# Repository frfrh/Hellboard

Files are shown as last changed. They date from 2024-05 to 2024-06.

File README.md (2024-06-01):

# Hellboard

This is a Macro board based on RP2040-zero and Micropython, meant for ordering Stratagems for Helldivers 2 by registering as a HID-Keyboard.

PXL_20240601_011015119 MP

## Folders

##### [Firmware](https://github.com/frfrh/Hellboard/tree/master/Firmware)

Contains the firmware to be loaded into the RP2040 and the Micropython project files.

##### [Hardware](https://github.com/frfrh/Hellboard/tree/master/Hardware)

Contains the 3D files for the case and the button caps.

##### [PCB](https://github.com/frfrh/Hellboard/tree/master/PCB)

Contains the project files for the PCB and the gerber files to order one.
Project is based on KiCad 8.0.2.

## Configuration

Currently the configuration of the board is hardcoded. This is meant to change in (near) future.

You can change the stratagems assigned to the buttons at the top on [main.py](https://github.com/frfrh/Hellboard/blob/master/Firmware/main.py) by replacing the macros for `button_2_1`, `button_2_2`, `button_2_3` and `button_2_4`.

You can change the directional keys in https://github.com/frfrh/Hellboard/blob/master/Firmware/libs/macro.py.

You can change the modifyer key in https://github.com/frfrh/Hellboard/blob/master/Firmware/libs/helldiver.py. `modifierUseToggle = True` means that the button will only be pressed once to open the menue, `modifierUseToggle = False` means that the button stay pressed while entering the macro.

## Build your own

You can use the gerber files in [PCB/gerber](https://github.com/frfrh/Hellboard/tree/master/PCB/gerber) to order your own PCBs or order it directly from https://aisler.net/p/AHPZGPKK.

You will also need the following parts:

| Part | Amount | Link |
| - | - | - |
| RP2040-Zero | 1 | [link](https://www.waveshare.com/rp2040-zero.htm) |
| 0,96" OLED Display 128x64 | 1 | [link](https://de.aliexpress.com/item/1005005970901119.html) (the 26.7mm variant, blue PCB) |
| Kailh boxed switches | 8 | [link](https://www.caseking.de/ducky-kailh-box-navy-switches-mechanisch-3-pin-clicky-mx-stem-85g-110-stueck-gakc-444.html) |
| Kailh hot-swap socket | 8 | [link](https://de.aliexpress.com/item/1005006146911562.html) |
| WS2812b-2020 LED | 8 | [link](https://de.aliexpress.com/item/10000006244752.html) |
| N-Channel MOSFET[^levelshifter] | 1 |  |
| 10K 0805 resistor[^levelshifter] | 2 |  |
| M93C86-WMN6P EEPROM[^eeprom] | 1 | [link](https://www.reichelt.de/eeprom-seriell-16kb-2kx8-1kx16-2-5-5v-so-8-m93c86-wmn6p-p280935.html) |
| Button caps[^buttoncaps] | 8 | [link](https://de.aliexpress.com/item/1005003992982246.html) |

You can find icons for the buttons [here](https://github.com/nvigneux/Helldivers-2-Stratagems-icons-svg).

## Setup

1. Install [Visual Studio Code](https://code.visualstudio.com/).
2. Install the [MicroPico extension](https://marketplace.visualstudio.com/items?itemName=paulober.pico-w-go).
3. Flash the firmware onto the RP2040:
    1. Press the button (`Boot`) and connect the Board to a PC.
    2. Copy the [UF2-file](https://github.com/frfrh/Hellboard/blob/master/Firmware/libs/3rd/firmware_with_HID_support.v.1.17.uf2) into the drive `RPI-RP2`.
    3. Re-Connect the board.
4. Load the following Python files into the board. In Visual Studio Code left click on the file, then right click the file and select `Upload current file to Pico`.
    - `Firmware/libs/3rd/keyboard.py`
    - `Firmware/libs/3rd/ssd1306.py`
    - `Firmware/libs/helldiver.py`
    - `Firmware/libs/macro.py`
    - `Firmware/main.py`

[^levelshifter]: I got them by desoldering them from a level shifter I had lying around. [link](https://de.aliexpress.com/item/1005006068381598.html)
[^eeprom]: The EEPROM is currently optional. This is meant for future configuration of the loaded stratagems, currently those are hardcoded.
[^buttoncaps]: I used the button caps from [here](https://de.aliexpress.com/item/1005003992982246.html) but replaced the internals with the ones from `Hardware/Kailh-Cap.stl` as the original ones are not translucent. Any button caps compatible with Kailh boxed switches should do.

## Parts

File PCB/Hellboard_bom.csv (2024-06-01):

Reference | Value | Datasheet | Footprint | Qty | DNP
C1,C2,C3,C4,C5,C6,C7,C8 | 4µ7 | ~ | Capacitor_SMD:C_0805_2012Metric_Pad1.18x1.45mm_HandSolder | 8 | Nicht bestücken
CR1 | M93C66-WMN6P | https://www.st.com/resource/en/datasheet/m93c46-w.pdf | footprints_M93C66-WMN6P:SO-8_STM | 1
D1,D2,D3,D4,D5,D6,D7,D8 | WS2812_Switch | https://cdn-shop.adafruit.com/product-files/4684/4684_WS2812B-2020_V1.3_EN.pdf | -- verschiedene Werte -- | 8
J1 | OLED-128x64 | https://www.datasheethub.com/ssd1306-128x64-mono-0-96-inch-i2c-oled-display/ | display:OLED-128x64 | 1
Q1 | AO3400A | http://www.aosmd.com/pdfs/datasheet/AO3400A.pdf | Package_TO_SOT_SMD:SOT-23 | 1
R1,R2 | 10k | ~ | LED_SMD:LED_0805_2012Metric_Pad1.15x1.40mm_HandSolder | 2
TP1,TP2,TP3,TP4,TP5,TP6,TP7,TP8,TP9 | TestPoint | ~ | TestPoint:TestPoint_Pad_D1.5mm | 9
U1 | rp2040-zero | https://www.waveshare.com/rp2040-zero.htm | mcu:rp2040-zero-smd | 1

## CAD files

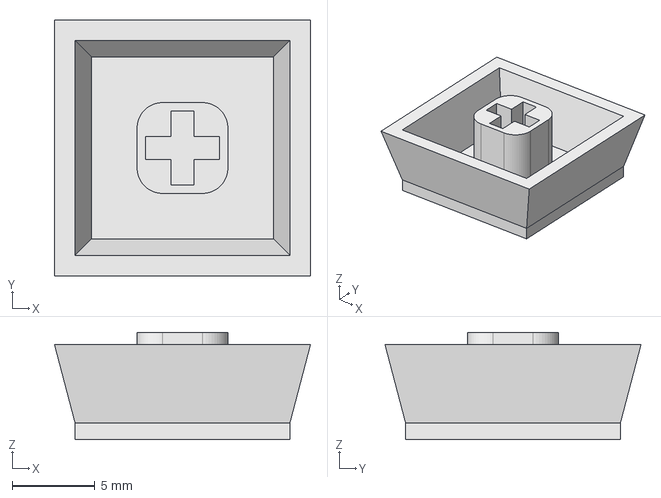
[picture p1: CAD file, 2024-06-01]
Hardware/Kailh-Cap.FCStd
15.5 x 15.5 x 6.50 mm

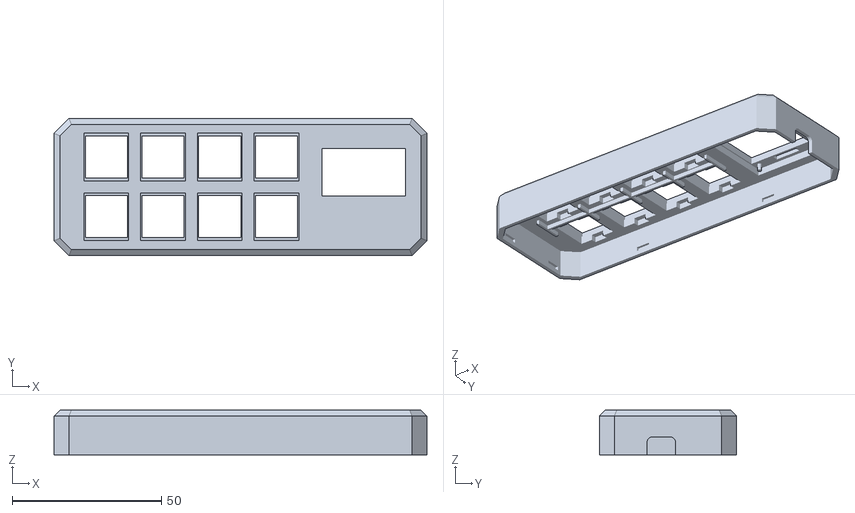
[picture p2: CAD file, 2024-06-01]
Hardware/Hellboard-Case-Top.stl
125.0 x 46.0 x 15.0

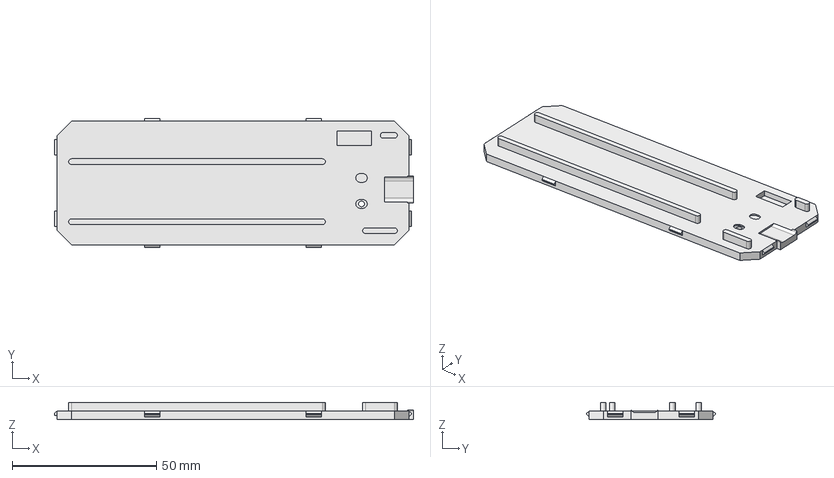
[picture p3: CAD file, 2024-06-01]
Hardware/Hellboard-Case.FCStd
124.3 x 44.6 x 6.00 mm

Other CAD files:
Hardware/Hellboard-Case-Bottom.stl
Hardware/Kailh-Cap.stl

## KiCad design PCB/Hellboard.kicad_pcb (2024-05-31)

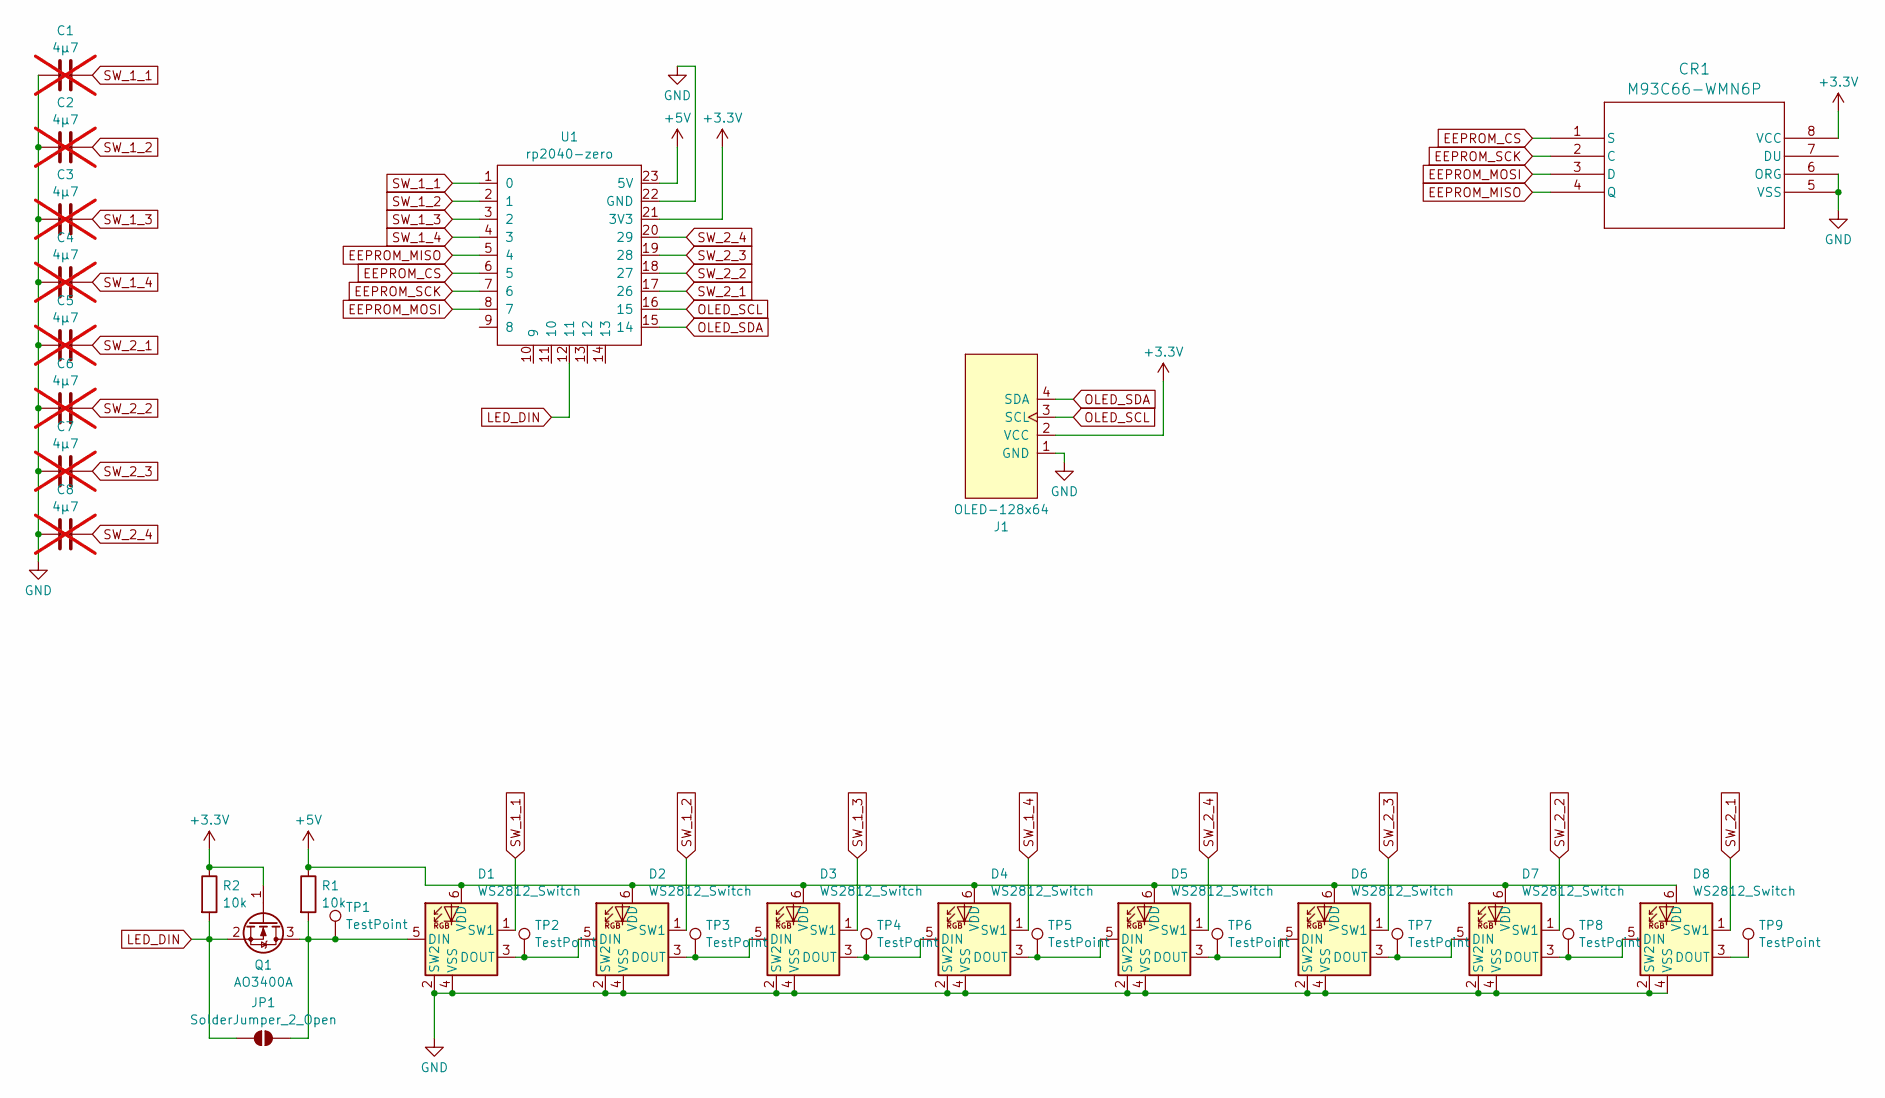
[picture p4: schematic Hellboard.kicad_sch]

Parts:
C1, C2, C3, C4, C5, C6, C7, C8: 4µ7; C_0805_2012Metric_Pad1.18x1.45mm_HandSolder; not fitted
CR1: M93C66-WMN6P; SO-8_STM
D1, D2, D3, D4: WS2812_Switch; Kailh_socket_MX_WS2812B_RL
D5, D6, D7, D8: WS2812_Switch; Kailh_socket_MX_WS2812B_LR
J1: OLED-128x64
JP1: SolderJumper_2_Open; SolderJumper-2_P1.3mm_Open_TrianglePad1.0x1.5mm
Q1: AO3400A; SOT-23
R1, R2: 10k; LED_0805_2012Metric_Pad1.15x1.40mm_HandSolder
TP1, TP2, TP3, TP4, TP5, TP6, TP7, TP8, TP9: TestPoint; TestPoint_Pad_D1.5mm
U1: rp2040-zero; rp2040-zero-smd

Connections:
+3.3V: CR1.8 (VCC), J1.2 (VCC), Q1.1 (G), R2.1, U1.21 (3V3)
+5V: D1.6 (VDD), D2.6 (VDD), D3.6 (VDD), D4.6 (VDD), D5.6 (VDD), D6.6 (VDD), D7.6 (VDD), D8.6 (VDD), R1.1, U1.23 (5V)
EEPROM_CS: CR1.1 (S), U1.6 (5)
EEPROM_MISO: CR1.4 (Q), U1.5 (4)
EEPROM_MOSI: CR1.3 (D), U1.8 (7)
EEPROM_SCK: CR1.2 (C), U1.7 (6)
GND: C1.1, C2.1, C3.1, C4.1, C5.1, C6.1, C7.1, C8.1, CR1.5 (VSS), CR1.6 (ORG), D1.2 (SW2), D1.4 (VSS), D2.2 (SW2), D2.4 (VSS), D3.2 (SW2), D3.4 (VSS), D4.2 (SW2), D4.4 (VSS), D5.2 (SW2), D5.4 (VSS), D6.2 (SW2), D6.4 (VSS), D7.2 (SW2), D7.4 (VSS), D8.2 (SW2), D8.4 (VSS), J1.1 (GND), U1.22 (GND)
LED_DIN: JP1.1 (A), Q1.2 (S), R2.2, U1.12 (11)
unnamed: D1.5 (DIN), JP1.2 (B), Q1.3 (D), R1.2, TP1.1
unnamed: D1.3 (DOUT), D2.5 (DIN), TP2.1
unnamed: D2.3 (DOUT), D3.5 (DIN), TP3.1
unnamed: D3.3 (DOUT), D4.5 (DIN), TP4.1
unnamed: D4.3 (DOUT), D5.5 (DIN), TP5.1
unnamed: D5.3 (DOUT), D6.5 (DIN), TP6.1
unnamed: D6.3 (DOUT), D7.5 (DIN), TP7.1
unnamed: D7.3 (DOUT), D8.5 (DIN), TP8.1
unnamed: D8.3 (DOUT), TP9.1
OLED_SCL: J1.3 (SCL), U1.16 (15)
OLED_SDA: J1.4 (SDA), U1.15 (14)
SW_1_1: C1.2, D1.1 (SW1), U1.1 (0)
SW_1_2: C2.2, D2.1 (SW1), U1.2 (1)
SW_1_3: C3.2, D3.1 (SW1), U1.3 (2)
SW_1_4: C4.2, D4.1 (SW1), U1.4 (3)
SW_2_1: C5.2, D8.1 (SW1), U1.17 (26)
SW_2_2: C6.2, D7.1 (SW1), U1.18 (27)
SW_2_3: C7.2, D6.1 (SW1), U1.19 (28)
SW_2_4: C8.2, D5.1 (SW1), U1.20 (29)

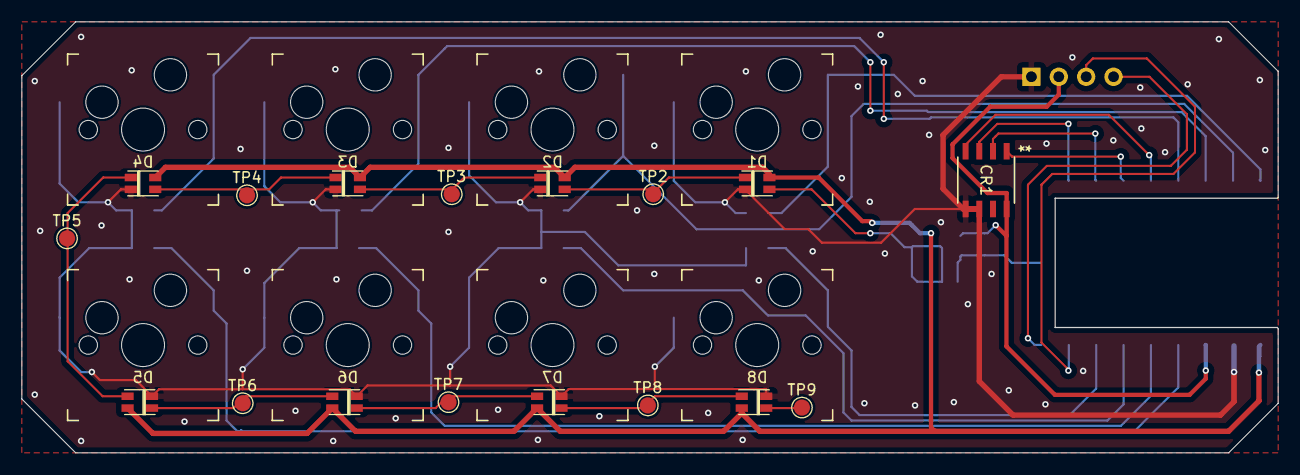
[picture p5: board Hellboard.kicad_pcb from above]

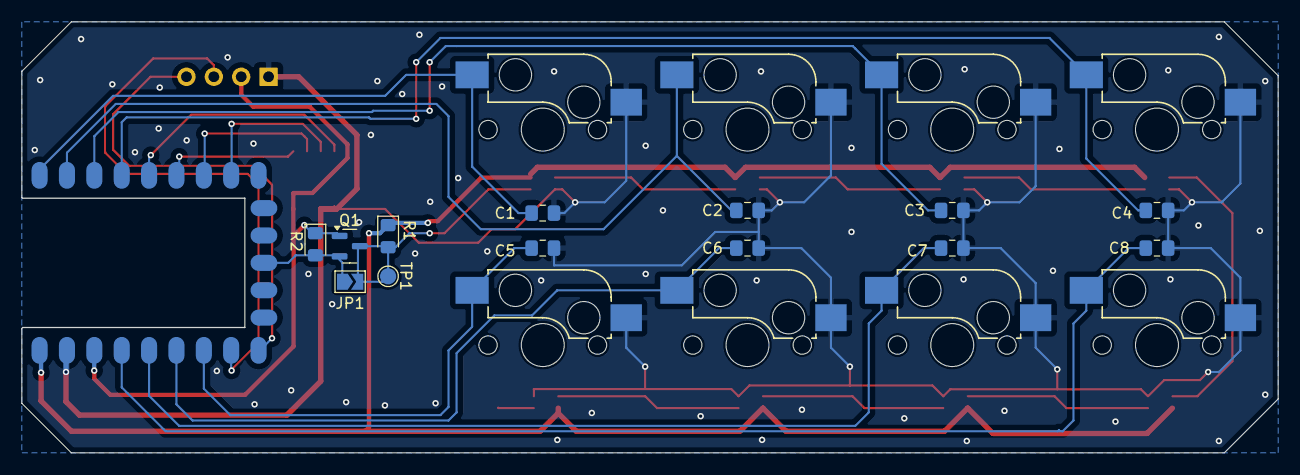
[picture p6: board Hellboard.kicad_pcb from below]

Board: 2 copper layers, 116.6 x 40.0 mm, 32 parts (14 on the bottom side), 27 nets.

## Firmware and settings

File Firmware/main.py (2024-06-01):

from machine import Pin, I2C, SPI
from ssd1306 import SSD1306_I2C
import keyboard
from helldiver import Hellboard, Hellbutton
from macro import Macros, Color
import framebuf
import time

k = keyboard.Keyboard()
board = Hellboard(k)

WIDTH = 128 # oled display width
HEIGHT = 64 # oled display height

BRIGHTNESS = 0x50
BRIGHTNESS_CONFIRM = 0x80

b1_4 = Pin(0, Pin.IN, Pin.PULL_UP)
b1_3 = Pin(1, Pin.IN, Pin.PULL_UP)
b1_2 = Pin(2, Pin.IN, Pin.PULL_UP)
b1_1 = Pin(3, Pin.IN, Pin.PULL_UP)

b2_1 = Pin(29, Pin.IN, Pin.PULL_UP)
b2_2 = Pin(28, Pin.IN, Pin.PULL_UP)
b2_3 = Pin(27, Pin.IN, Pin.PULL_UP)
b2_4 = Pin(26, Pin.IN, Pin.PULL_UP)

button_1_1 = Hellbutton(b1_1, Macros.Reinforce)
button_1_2 = Hellbutton(b1_2, Macros.Resupply)
button_1_3 = Hellbutton(b1_3, Macros.Reinforce)
button_1_4 = Hellbutton(b1_4, Macros.CYCLE)

button_2_1 = Hellbutton(b2_1, Macros.GrenadeLauncher)
button_2_2 = Hellbutton(b2_2, Macros.ShieldGeneratorPack)
button_2_3 = Hellbutton(b2_3, Macros.MortarSentry)
button_2_4 = Hellbutton(b2_4, Macros.Eagle500KGBomb)

row1List = []
row1List.append (Macros.SOSBeacon)
row1List.append (Macros.EagleRearm)
row1List.append (Macros.SuperEarthFlag)
row1List.append (Macros.SEAFArtilery)
row1List.append (Macros.UploadData)
row1List.append (Macros.SeismicProbe)
row1List.append (Macros.Hellbomb)
row1List.append (Macros.OrbitalIlluminationFlare)

colors = {}

time.sleep_ms(100)
displayReady = False
try:
    i2c = I2C(1, sda=Pin(14), scl=Pin(15))  # Init I2C using I2C0 defaults, SCL=Pin(GP9), SDA=Pin(GP8), freq=400000
    oled = SSD1306_I2C(WIDTH, HEIGHT, i2c, addr=0x3C) # Init oled display
    time.sleep_ms(100)
    oled.rotate(1)
    print("Display initialized")
    displayReady = True
except Exception:
    print("Display error " + str(Exception))

# Initialize SPI
spiLed = SPI(1,
            baudrate=2500000,
            polarity=1,
            phase=1,
            bits=8,
            firstbit=SPI.MSB,
            sck=Pin(10),
            mosi=Pin(11),
            miso=Pin(12))

# 1/2 mix
def byteToData(byte):
    # Initialize all `0`
    data = bytearray(b'\x92\x49\x24')
    data[0] |= 0x01 if (byte & 0x20) else 0
    data[0] |= 0x08 if (byte & 0x40) else 0
    data[0] |= 0x40 if (byte & 0x80) else 0
    data[1] |= 0x04 if (byte & 0x08) else 0
    data[1] |= 0x20 if (byte & 0x10) else 0
    data[2] |= 0x02 if (byte & 0x01) else 0
    data[2] |= 0x10 if (byte & 0x02) else 0
    data[2] |= 0x80 if (byte & 0x04) else 0
    return data

def rbgToData(r, g, b):
    data = bytearray()
    # print ("Adding R:" + str(r) + ", G:" + str(g) + ", B:" + str(b))
    data.extend(byteToData(g))
    data.extend(byteToData(r))
    data.extend(byteToData(b))
    return data

def intToData(color):
    # print ("Adding color: 0x{0:02x}".format(color))
    return rbgToData(((color>>16)&0xFF),
                     ((color>>8)&0xFF),
                     ((color)&0xFF))

buttons = []
buttons.append(button_1_4)
buttons.append(button_1_3)
buttons.append(button_1_2)
buttons.append(button_1_1)
buttons.append(button_2_1)
buttons.append(button_2_2)
buttons.append(button_2_3)
buttons.append(button_2_4)

index = 0
lastTime = time.ticks_ms()
switchTimeout = 300
brightnessConfirm = (BRIGHTNESS_CONFIRM<<16) + (BRIGHTNESS_CONFIRM<<8) + (BRIGHTNESS_CONFIRM)

def doButtons():
    global index
    global lastTime
    pressed = False
    for button in buttons:
        if button.isPressed():
            if button.getMacro() == Macros.CYCLE:
                if (lastTime + switchTimeout) < time.ticks_ms():
                    lastTime = time.ticks_ms()
                    index = index + 1
                    if index >= len(row1List):
                        index = 0
                    pressed = True
                    button_1_3.setMacro(row1List[index])
                    print("Button 1-3 set to: \"" + button_1_3.getMacro().getName() + "\"")
            else:
                print(button.getMacro())
                board.sendMacro(button.getMacro())
                pressed = True

    return pressed

def doDisplay():
    global displayReady
    if displayReady:
        oled.fill(0)
        oled.text(button_1_3.getName(),0,4)
        oled.text("----------------",0,18)
        oled.text(button_2_1.getName(),0,24)
        oled.text(button_2_2.getName(),0,34)
        oled.text(button_2_3.getName(),0,44)
        oled.text(button_2_4.getName(),0,54)
        oled.show()

def doLed(buttonPressed):
    global brightnessConfirm
    data = bytearray()
    if buttonPressed:
        for x in range(8):
            data.extend(intToData(brightnessConfirm))
    else:
        for button in buttons:
            data.extend(intToData(colors[button.getMacro().getColor()]))
    spiLed.write(data)


# MAIN 

print (spiLed)
print ("Brightness set to " + str((BRIGHTNESS * 100) / 255) + "%")
button_1_3.setMacro(row1List[index])

colors[Color.YELLOW] = (BRIGHTNESS<<16) + (BRIGHTNESS<<8)
colors[Color.RED] = (BRIGHTNESS<<16)
colors[Color.GREEN] = (BRIGHTNESS<<8)
colors[Color.BLUE] = (BRIGHTNESS)
colors[Color.WHITE] = (BRIGHTNESS<<16) + (BRIGHTNESS<<8) + (BRIGHTNESS)

while True:
    pressed = doButtons()
    doDisplay()
    doLed(pressed)
    
    time.sleep_ms(50)
    

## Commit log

2024-05-31 adding Hellboard PCB
    [Hellboard.kicad_pcb, Hellboard.kicad_sch]
2024-06-01 add case
    [Hellboard-Case-Bottom.stl, Hellboard-Case-Top.stl, Hellboard-Case.FCStd]
2024-06-01 add datasheets
    [Hellboard.kicad_sch]
2024-06-05 fix 120mm barrage
2026-10-15 Detect Helldivers 2 window and monitor (P1)
    - IGameLocator with GameSnapshot/GameLocation model in Core
    - Monitor selection (largest intersection, nearest, override) and
    window mode rules with unit tests, incl. negative coordinates
    - Win32GameLocator: WinEvent hooks + 1 s polling on its own message
    loop thread, per-monitor DPI aware independent of the host manifest
    - Game section in the status window
    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
2026-10-15 Capture the game monitor via Desktop Duplication (P2)
    - Frame, IFrameSource and GameFrameGrabber in Core (platform-neutral)
    - DesktopDuplicationFrameSource: one duplication session per monitor,
    staging texture, region readback, recreation on access loss
    - Status window: live preview at 2 frames/s, black-frame warning,
    snapshot saving and opening the snapshot folder
    - Unit tests for Frame and GameFrameGrabber
    - Plan: Desktop Duplication replaces Windows.Graphics.Capture as the
    primary capture path; P2 accepted (0.25 % CPU at 2560x1440, 2 fps)
2026-10-15 Add local scene tests and ready status detection (P4, part 1)
    - OpenCvSharp4 for test image loading; LocalScenes loads the local
    screenshots, crops the client area and rescales to 720p-4K in memory,
    skipping scenes whose image is missing
    - tests/testData/scenes.json with expected results (images stay local)
    - ReadyStatusDetector: yellow share of the ready button's inner area,
    Prepare 6-8 %, Ready 71-73 % on all scenes and resolutions
    - stratagem-names-de.md: English/German names of 89 stratagems
    - Plan: stratagem coverage decision, test strategy
2026-10-15 Detect the loadout screen from structural cues (P4, part 2)
    - LoadoutScreenDetector: ready button (yellow outline or fill, block-wise
    diagonal stripe check independent of the label), player slot raster
    (gray inner edges) and fixed mission frames as supporting cue
    - Center-based offset correction (Ready fill is smaller than the
    Prepare outline), verified with shifted captures
    - Tests on all local scenes at 720p-4K: 30 loadout screens detected,
    65 other screens rejected
    - Plan updated with the implemented cues and measured scores
2026-10-15 Classify stratagem slots with SVG-rendered templates (P4, part 3)
    - StratagemIcon (ids are slugs of the repository file names) and a
    minimal StratagemIconDownloader for a local copy of the icon repo
    - SvgRenderer (Svg.Skia 5.1.1 on SkiaSharp 3.119, as used by Avalonia)
    - StratagemSlotClassifier: canonical 64 px, shift tolerance, empty
    detection, score/margin acceptance; slot styles for player slots and
    framed mission slots measured on captures
    - Tests: player and mission slots correct in all scenes at 720p-4K
    against all 109 icons; icons cached in tests/testData/local/icons
2026-10-15 Add recognition pipeline and loadout lock-in (P4, part 4)
    - LoadoutRecognizer: screen detection, ready status and parallel slot
    classification per frame; coarse-to-fine matching and per-slot result
    cache (unchanged loadout 2-11 ms, new loadout 75-140 ms)
    - LoadoutTracker: stable candidate, Prepare->Ready lock-in, screen-exit
    lock-in, Ready->Prepare reset, debouncing; unit and replay tests
    - LoadoutPipeline background loop, StratagemIconStore (runtime icon
    download into the data directory), LoadoutHistory (loadouts.jsonl)
    - Status window shows screen, ready state, stratagems and last lock-in
2026-10-15 Add manual trigger and image file analysis (P4, part 5)
    - Hotkey model and IGlobalHotkeys; Win32GlobalHotkeys via RegisterHotKey
    on a dedicated message thread (no keyboard hook, no input injection)
    - RecognitionOptions (mode, Ctrl+Shift+F9, test mode, snapshot saving)
    - LoadoutPipeline executes manual bursts (5 frames, majority vote) and
    file analyses on its own thread; forced recognition with warning when
    the loadout screen is not detected; manual-only mode
    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
2026-10-16 Record firmware decisions F1-F10
    - F1-F9 agreed; F3 modified: loadouts and settings stay in RAM and are
    written to flash only via "Set as default" in the Companion
    - F10 (switch to official MicroPython) agreed as an isolated phase P7b
    with test plan and rollback to v1.17
    - Hardware constraint: the EEPROM is not populated; only RP2040-Zero
    RAM and flash are available
2026-10-16 Add Hellboard protocol v1 and board spike
    - doc/spec/hellboard-protocol.md: newline-delimited JSON over USB CDC;
    ping, setLoadout (complete stratagem definitions), getState,
    setConfig, saveDefault (flash only on "Set as default"),
    enterUpdateMode, hello event, error codes
    - tools/board-spike: spike.py (runs from RAM via raw REPL) and
    Run-BoardSpike.ps1; all checks passed on the real board with
    MicroPython 1.17 (non-blocking stdin, json, sha256, base64,
    os.rename, machine.bootloader)
    - Plan: protocol linked, P7 runs on the existing v1.17 build
2026-10-16 Add Hellboard link on the PC side (P5)
    - HellboardClient: JSON lines with id/ack, 500 ms timeout, 3 retries
    with the same id, non-protocol output ignored, hello event
    - SerialHellboardConnection (System.IO.Ports), RegistrySerialPortDiscovery
    (USB VID 2E8A), in-process SimulatedHellboard
    - HellboardLink: connect, heartbeat, resend after reconnect or board
    restart, send only changed loadouts, release the port of boards
    without protocol (verified live with the old firmware), dry run
    - LoadoutTransferBuilder: full stratagem names (shortened only on the
    board's display), multi-function modes, not-transferable report
    - assets/catalog.seed.json: 109 stratagems, 83 with input sequences
    f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
2026-10-16 Persist settings in config.json and apply them live (P6, step 1)
    - CompanionSettings (general, game, recognition, hellboard,
    multiFunction) stored by SettingsStore in %APPDATA%; defaults for
    missing values, atomic writes, broken file kept as .invalid
    - The option objects used by the services are the settings sections;
    HellboardLink.ApplySettings reconnects on mode/port changes and
    resends a changed multi-function list; the hotkey is re-registered
    - Tests for the store and for live switching of the Hellboard link
2026-10-16 Rework the main window into tabs and add autostart (P6, steps 2-3)
    - Overview tab for demonstrations: game -> recognition -> Hellboard
    status chain, loadout tiles with stratagem icons (live, last locked or
    from the previous session), multi-function list (with preview),
    warnings, "Recognize loadout now" and "Set as default"
    - Settings tab: recognition mode, hotkey, test mode, trigger frames;
    Hellboard connection (USB, simulator, dry run) and port;
    multi-function mode and fixed-list editor with icons; start with
    Windows; game process - saved and applied immediately
    - History tab with icons; Diagnostics tab with the former content
    - StratagemImages renders UI icons from the SVGs; Re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
2026-10-16 Show recognition problems in the history with an important-only view
    - History lines are typed ("entry": loadout | problem); older lines
    without type are read as loadouts
    - Pipeline records problems: unrecognized stratagem with a screenshot
    of the slot, input sequence unknown (once per session), loadout screen
    not detected on a manual trigger (reduced screenshot), recognition
    errors (rate-limited)
    - History tab: filter "Important" (default: Ready, manual, problems) or
    "Everything", saved in config.json; problem entries show the
    screenshot or the stratagem icon
    - Tests for the history format and the problem recording
2026-10-16 Add doc/stratagems.md as the single source of stratagem input codes
    115 stratagems with id, designation, code, current firmware macro and
    notes for disputed or unverified codes (checked against wiki.gg,
    DiversHub and the Fandom wiki). The software README and the plan point to
    it; deriving the seed catalog and firmware macros from it is not wired up
    yet. SSSD Delivery uses the Fandom code until further notice.
2026-10-16 Make doc/stratagems.json the single source of stratagem data
    - doc/stratagems.json: 115 stratagems with id, name, designation,
    category, code (U/D/L/R), firmware macro and notes, plus the
    category -> LED color table; readable by MicroPython's json module
    - doc/stratagems.md now describes the format, rules and decisions
    - The companion embeds the JSON and builds its catalog from it with
    validation; assets/catalog.seed.json is removed, so every stratagem
    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
2026-10-16 Require the mission stratagem frames for loadout screen detection
    The screen after a mission has a yellow "back to ship" button at the
    ready button position and, with the player menu open, gray rows where
    the slots are. It was taken for the loadout screen and produced empty
    lock-ins and false "not recognized" problems. The beige frames of
    Reinforce, SOS Beacon and Resupply are present in every mission and are
    now required; they are checked with a small band across the edge so the
    1 px frame at 720p still counts (loadout 0.71-1.00, other screens <= 0.24).
2026-10-16 Add the firmware upload tool (P7 step 1) and a user stratagem list
    Firmware upload (decision F11, plan section 6.10):
    - MicroPythonRawRepl, FirmwareBundle and FirmwareInstaller in Core: files
    are written as *.new, verified by SHA-256 on the board, then swapped in
    (old files kept as *.bak); failures remove the new files or restore the
    old ones. Tested against a simulated board and on the real Hellboard.
    - Firmware/manifest.json lists the files for the board, incl.
    doc/stratagems.json; tools/hellboard-upload installs them.
    - F11 and the P7 order recorded in the plan; stratagems.json must keep
    one stratagem per line (checked by a test).
    User stratagem list:
    - StratagemCatalog merges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
2026-10-16 Restructure the firmware into modules with id-based config (P7 step 2)
    - Firmware split into app, hid, leds, display, config, stratagems and log
    (decision F6); main.py only starts the app. Behavior unchanged, tested
    on the real board.
    - Button assignment and key settings in Firmware/config.json, stratagems
    referenced by id and read line by line from stratagems.json (F11);
    macro.py, helldiver.py and the firmwareMacro field are removed.
    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
2026-10-16 Add the Hellboard protocol to the firmware and a Hellboard tab (P7 step 3)
    Firmware:
    - protocol module: newline JSON over USB serial, read non-blocking, also
    between key events; ping, getState, setLoadout, setConfig, saveDefault,
    saveConfig, getLog, enterUpdateMode, hello and log events (F1, F2, F12)
    - configuration incl. fixed buttons can be changed at runtime and saved
    to saved.json on request (F13); CPython tests in Firmware/tests
    Companion:
    - BoardOptions / BoardConfiguration: the board configuration is adopted
    on the first connect, then sent after every connect and change
    - Hellboard tab: connection, configuration with a separate "Save
    configuration on the Hellboard" button,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
2026-10-17 Show transfer feedback on the Hellboard (P7 step 4, F4)
    - The display separator line shows "Loadout received", "Default saved",
    "Config saved", "PC connected" or "Transfer error" for 2 s and ends
    with "PC" while the Companion is connected
    - LEDs flash twice in their colors on receipt/save, red on errors
    - Names are fitted to the display line in one function (display.fit),
    prepared for a scrolling text
    - Firmware tests cover the feedback; verified on the real board
2026-10-17 Install firmware updates from the Companion (P7 step 7)
    - Firmware files are embedded in the Companion; the board gets a
    stratagem list generated from the catalog incl. the user's own entries
    - Firmware version set once in Firmware/manifest.json, written to
    version.json on the board and reported by ping
    - HellboardLink.UpdateFirmwareAsync stops the board (enterUpdateMode or
    Ctrl-C for old firmware), installs via the raw REPL and reconnects
    - Hellboard tab: firmware versions, update with confirmation and progress
    - Fix: before any loadout is locked, the multi-function list of the
    settings is sent with the board's current slots, so it reaches the
    board right after connecting and afte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
2026-10-17 Add a stratagem editor and icon placeholders (P8)
    - Stratagems tab: all catalog entries and new icons, search and "only
    without code" filter; edit name, category and code (arrow buttons or
    arrow keys/WASD, 3-10 arrows, warning for duplicate codes)
    - Changes are stored in the user list (UserStratagemList, one entry per
    line) and apply without a restart: the catalog is replaced in place,
    the Hellboard link re-sends the loadout, pickers update
    - "Remove my change" restores built-in codes; export/import of the list
    - Stratagems without an icon in the icon repository get a placeholder
    tile in their category color with their initials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
2026-10-17 Count downloads thread-safely in the icon updater tests
    The fake GitHub counted with ++ while the downloader loads several icons in parallel, so a lost increment made publish.ps1 fail now and then.
2026-10-17 Fix stale protocol answers after reconnecting and error answers on the board
    - The Companion started every connection with request id 1, while the
    board remembers the answers of recent ids for retries - across
    connections. After a reconnect requests got old answers without being
    executed (configuration not applied, pings failing every ~30 s). The
    client now starts at a random id; the firmware forgets its remembered
    answers on ping, which starts every connection.
    - ProtocolError called Exception.__init__, which MicroPython does not
    have, so every error answer of the board became internal_error.
2026-10-17 Port the firmware improvements of branch changesMartin (firmware 2.1.1)
    Ideas from the branch changesMartin, re-implemented for the new firmware:
    - F14: a stratagem button sends once per press (debounced); the cycle
    button goes forward on a short and backward on a long press; main loop
    every 10 ms
    - F15: separate key timings (menu delay, arrow press, pause) and a screen
    saver against OLED burn-in, set on the Hellboard tab
    - F16: scrolling of long names (off / back and forth / continuous ticker)
    and a start-up logo matching the Companion icon (generated by
    tools/display-logo)
    Also: the overview shows outdated (yellow) and incompatible (red) board
    firmware; Firmware/.gitignore keeps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
2026-10-17 Plan the UI polish: background, wrapping status and multi-function list
    Plan only, not implemented: four procedurally drawn background options
    with rendered previews (wide and minimum width), a wrapping status chain
    with chevron entries, multi-function entries grouped by origin in thin
    frames and wrapping, and "Recognize loadout now" only while the game runs.
    Open questions for the user are listed at the end.
2026-10-17 Plan short status texts with a detail line for the status chain
    The status texts sit in horizontal stack panels, so they never wrap and
    run out of their fields at narrow widths. The plan now gives each entry
    a short text plus an optional wrapping detail line.
2026-10-17 Recognize icons the game draws differently from their SVG
    - Wider shift search (6 px) at the exact scale of the slot; the Guard Dog
    Rover sits 5 px higher in the game than in its SVG.
    - Close candidates (Guard Dogs, shield backpacks, minefields) are decided
    by the pixels where their templates differ, compared at the position of
    the stronger match, and only when the icon as a whole fits well.
    - Second pass with icons 5 % smaller and larger (Warp Pack).
    - Mission-only stratagems (SEAF Artillery etc.) are no longer compared in
    the player slots.
2026-10-17 Let the user assign game images to stratagems the icons do not match
    An unrecognized slot in the History tab can be assigned to a stratagem
    ("This is ..." / "Use as reference"). The slot image is stored locally in
    %LOCALAPPDATA%\HellboardCompanion\references and replaces the SVG of that
    stratagem in the recognition and in the user interface (without the slot
    frame, background transparent). This covers icons the game draws with a
    badge (EAT-17, EAT-411) and wrong icons in the icon repository (Bastion
    MK XVI shows the Maelstrom).
    The Stratagems tab shows which stratagems have reference images, filters
    them ("Only with reference") and removes them.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
2026-10-17 Polish the main window: hex background, wrapping status and multi-function groups
    - Background drawn for the window size: hex grid, faint yellow glow and
    hazard stripes fading out along the bottom edge.
    - Status chain without arrows; each entry has a short text and a smaller
    detail line, entries wrap as a whole and show the full text as tooltip
    (long texts used to run out of their fields).
    - Multi-function list in framed groups "Fixed list" / "Detected" that wrap.
    - "Recognize loadout now" only while the game runs (disabled while
    minimized), tray entry likewise; the hotkey without the game shows
    "Helldivers 2 is not running".
    - Screenshot tool renders any width and a variant with l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
2026-10-18 Let the firmware update stop an old firmware that never reads the port
    The old firmware (MicroPython 1.17 with HID) never reads the USB serial
    port. Everything the Companion sent stayed in the board's 256-byte USB
    buffer: the protocol check sent up to four pings and was repeated every
    30 s, so after about half a minute the buffer was full and the Ctrl-C of
    the firmware updater could not get through any more – the update failed
    with "The semaphore timeout period has expired".
    - The first check sends a single ping and waits 4 s for the answer (a
    firmware that is still starting reads it a moment later).
    - A board that does not answer is not checked again until it is
    unplugged and plugged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
2026-10-18 Capture HDR and 10-bit desktops in the colors of the game
    On a Windows 10 PC with HDR the captured image looked like colored noise
    (the 16-bit image was read as 8-bit), and once read correctly it was far
    too bright: the slot gray 47 came out as 85, so the loadout screen was
    not detected.
    - Desktop duplication asks for 8-bit BGRA or 16-bit float
    (DuplicateOutput1), falling back to DuplicateOutput.
    - 16-bit HDR images are converted with the monitor's SDR white level
    ("SDR content brightness", from the display configuration), 10-bit
    images are converted as well.
    - The log shows the format and the SDR white level.
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2026-10-19 Add the wiki layer to the stratagem catalog
    Step 2 of Software/doc/spec/wiki-source-plan.md: the Companion reads the
    stratagem table of helldivers.wiki.gg at runtime.
    - WikiStratagemStore keeps the last table in the data directory, checks
    at start and every 6 h at most once a day (or on "Check now") and
    remembers dismissed proposals.
    - StratagemCatalog merges built-in list < wiki layer < user list: new
    stratagems and missing codes come from the wiki, designations and
    short names follow it, a different code of a known stratagem is only
    proposed. WikiMatching is shared with stratagem-sync.
    - Stratagems tab: proposals with "Take over wiki code" (user list) and
    "Keep current code",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
2026-10-19 Use the stratagem icons of helldivers.wiki.gg
    Steps 3 and 4 of Software/doc/spec/wiki-source-plan.md: the icon
    repository nvigneux/Helldivers-2-Stratagems-icons-svg is replaced.
    - WikiIconDownloader asks the MediaWiki API for URL and SHA-1 of every
    icon the catalog needs and downloads only new and changed files, at
    most once a day. Where the wiki has only the icon with background
    (Meltagun), the plain icon is derived as PNG (SvgRenderer).
    - StratagemIconStore updates the wiki table first, maps icons to catalog
    ids, keeps icons shared by several stratagems out of the recognition
    and removes the old icon folder.
    - The wiki icons fill the slot: SlotStyle 1.0 (player), 0.991 (mission)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
2026-10-20 Record the decisions for the choice by hand
    All open questions of the plan are answered: rule "stays until the game
    shows something different", flyout picker, slots swap on duplicates,
    delayed history entry, hint line plus README section. The multi-function
    list and German names in the search are left for later.
    Claude-Session: https://claude.ai/code/session_01W7tmrStwCwkZZ3U3wYebEB
2026-10-20 Lock in loadouts chosen by hand
    New lock source ByHand with per-slot hand marks. A hand choice stays
    until the game shows something different: an automatic lock-in with
    the content it corrected is skipped (manual-selection plan 3.2).
    "Back to recognized" locks the last recognized loadout in again.
    Hand choices are written to the history after 30 s, so several tiles
    set in a row give one entry; the pending entry is shown at once.
    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
2026-10-20 Add the stratagem picker logic for the choice by hand
    HandChoice sets one player slot of the shown loadout (swapping with a
    slot that already holds the stratagem) and lists the recently used
    stratagems. StratagemPickerViewModel holds search, category chips,
    recently used row and the grid for the flyout; the filter is a pure
    function. Mission stratagems are not offered for player slots.
    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
2026-10-20 Choose stratagems by hand in the overview
    The four large tiles are buttons: a click opens a flyout with search,
    category chips, recently used stratagems and the grid; the choice is
    sent to the Hellboard at once. Tiles set by hand show a pencil and
    "set by hand", the title names the slots, the status says "Set by
    hand". "Back to recognized" sends the last recognized loadout again.
    While nothing was recognized, a hint line points to the tiles.
    The screenshot tool works again with the wiki icon store and has a
    "hand" mode that also renders the picker. BETA-README explains what
    to do if the recognition does not work.
    Claude-Session: https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
2026-10-21 Saves follow the transfer feedback, the LED flash turns white
    "Default saved" and "Config saved" show the hellpod animation as well
    when it is selected; with 'flash' all LEDs flash white, errors always
    flash red.
2026-10-24 Right-click on a tile set by hand resets the slot to the recognized stratagem
    The hand choice now stores per slot what the recognition had there
    (LockedLoadout.Recognized, written to loadouts.jsonl), so the reset also
    works for the loadout of a previous session after a restart. A swap is
    undone as well; resetting the last hand choice counts as Back to recognized.
2026-10-24 Keep the detected multi-function stratagems after a restart
    Before a loadout is locked in, the multi-function list sent to the board
    was built from the fixed list only, so the mission stratagems detected in
    the last session disappeared from the board. The last loadout of the
    history now supplies them (fixed list plus detected, as the overview
    already showed); the player slots of the board stay unchanged.
